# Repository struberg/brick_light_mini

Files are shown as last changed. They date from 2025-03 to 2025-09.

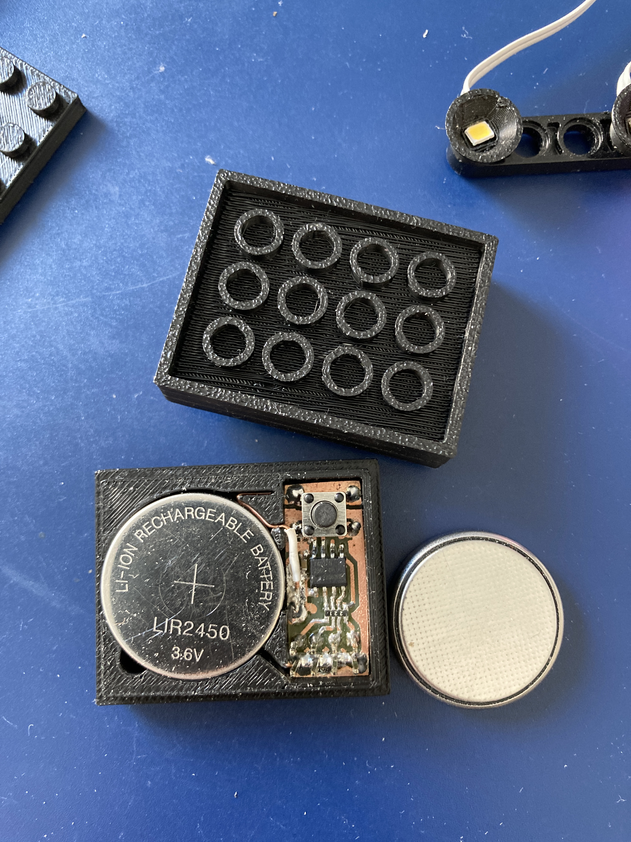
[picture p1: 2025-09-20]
pics/IMG_5117.JPG

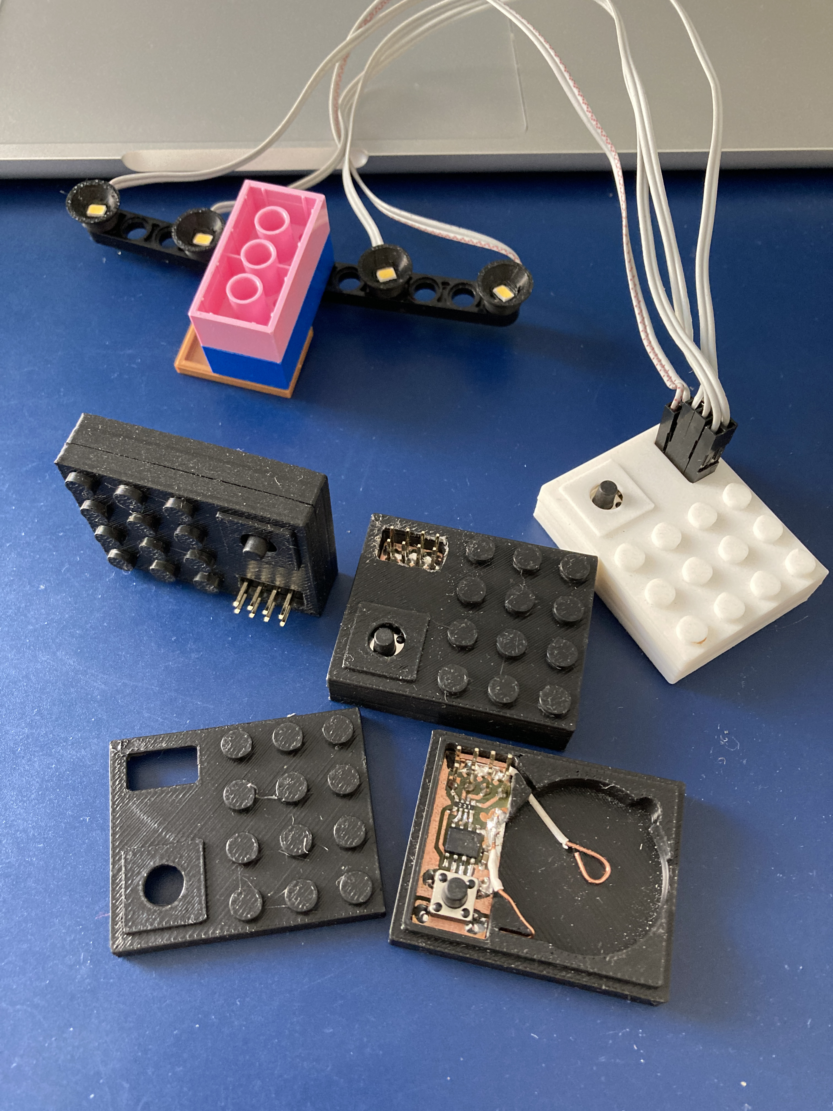
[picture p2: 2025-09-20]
pics/IMG_5110.JPG

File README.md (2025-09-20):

# Lightning system for game bricks

This is a game brick compatible lightning solution to control 4 LEDs.
The repo contains the controller box source code, schematic and PCB plus all the 3d printer models to create your own enclousure and lamps.
The PCB is deliberately single sided and can easily be etched by yourself with Natriumpersulfate.
Ofc if someone likes to create a double sided PCB to be made at Aisler etc then don't hesitate to ship a PR.

The schematic is based on a 0-series ATtiny-402, but a 202 will likely do fine as well.
A rechargable LiIon LIR2450 acts as power source.
The 2450 size is a good compromise between juice and size. 
Connectors are simple 2x1 Dupont types.

The only somewhat non-jellybean part is the 4x220R 0603 resistor array. 
I had to use it because 4 separate resistors would have been too big to fit on the PCB.
You can get those for very cheap from aliexpress or mouser though.

## How to connect the LEDs

You can use any standard low power white or colored LEDs.
The maximum output per LED is around 15 mA.

Place the controler box so that the button is on the lower left side and the LED connectors are on the left upper side.
The top row of the pins is all ground and internally connected.
The lower row of the pins are the positive LED pins, starting with 1 on the left side.

```
  x  x  x  x
  |  |  |  | 
  1  2  3  4  
  |  |  |  |
  x  x  x  x
```
## How to use

* single click: switch LED 1 on or off
* double click: switch LED 2 on or off
* triple click: switch LED 3 on or off
* quadruple click: switch LED 4 on or off

The device will switch off all LEDS and go to sleep after around 5 Minutes of not using the button.
This prevents emptying the battery when one forgets to turn off all lights.
The sleep current is in the µA range, I measured from 0.2µA to 1.5µA
The device will turn on again simply by pressing the button.

Have fun!

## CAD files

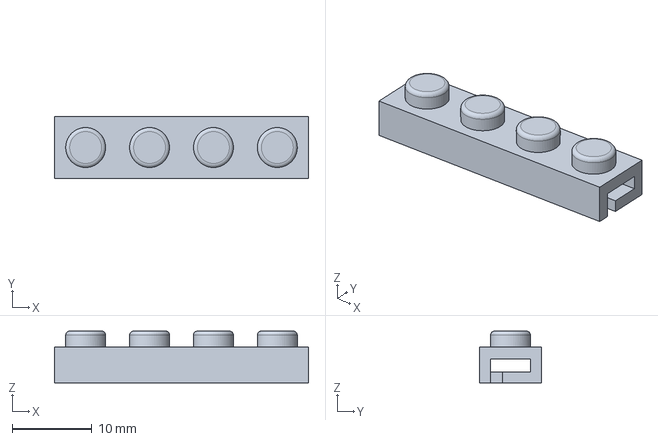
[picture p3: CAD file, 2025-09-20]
freecad/Kabelhalter 4x1.FCStd
31.8 x 7.80 x 6.50 mm

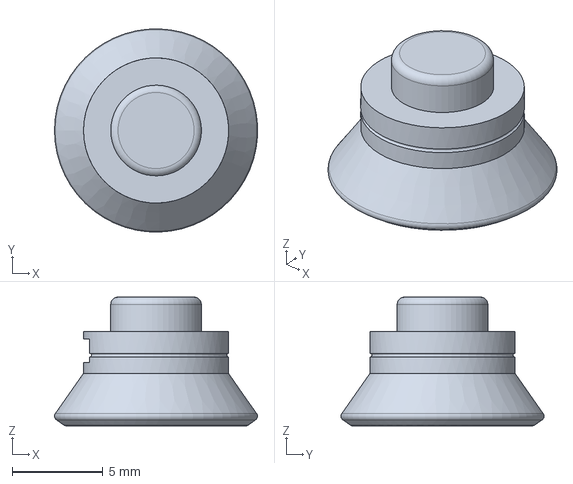
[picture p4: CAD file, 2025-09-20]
freecad/LampeOben.FCStd
11.2 x 11.2 x 7.10 mm

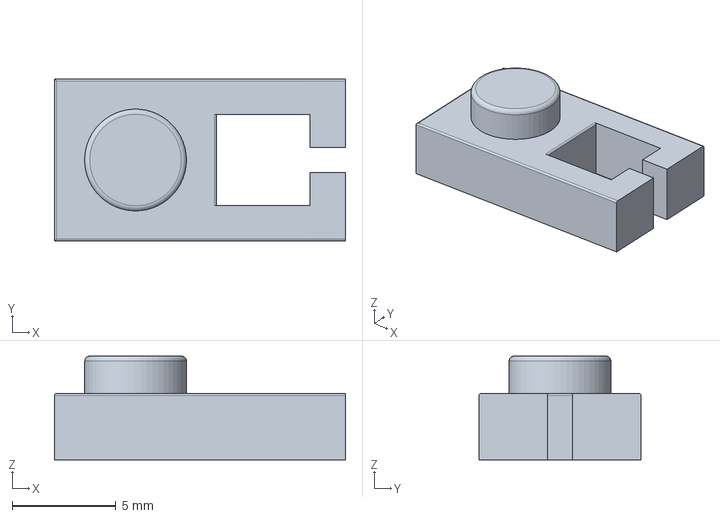
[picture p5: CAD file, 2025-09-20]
freecad/KabelhalterUnten_v.FCStd
14.0 x 7.80 x 5.00 mm

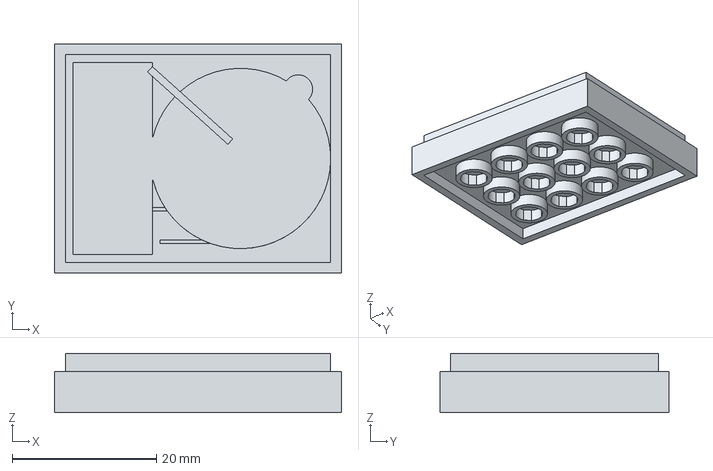
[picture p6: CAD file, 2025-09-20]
freecad/LegoBat_CR2450-bottom.step
39.8 x 31.8 x 8.20 mm

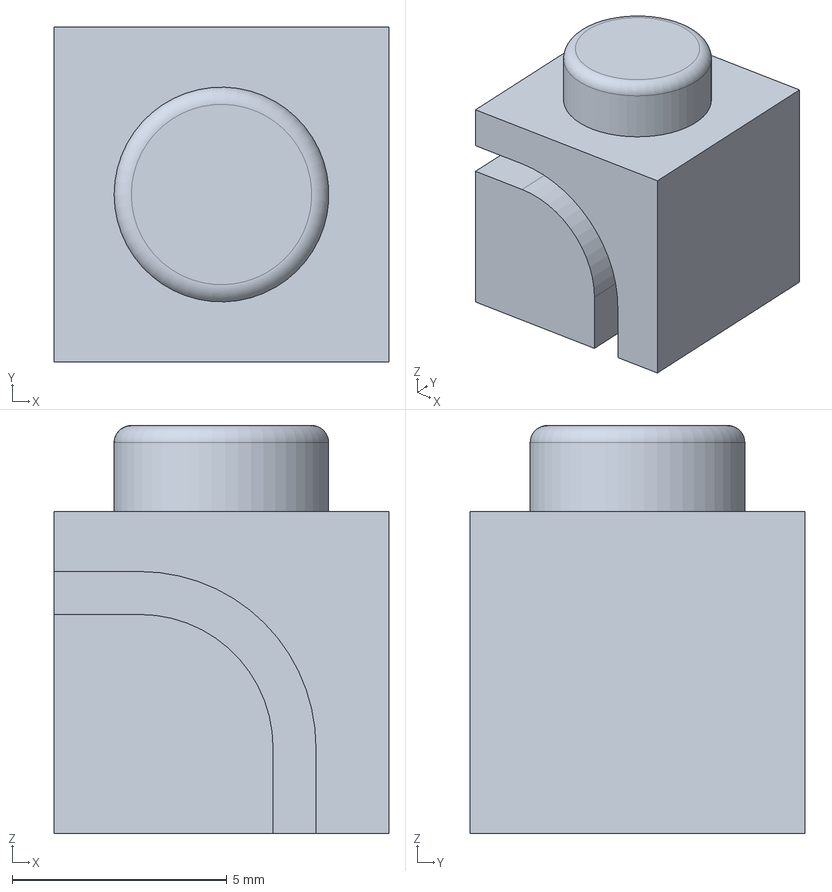
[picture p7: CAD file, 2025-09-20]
freecad/KabelhalterEcke.FCStd
7.80 x 7.80 x 9.50 mm

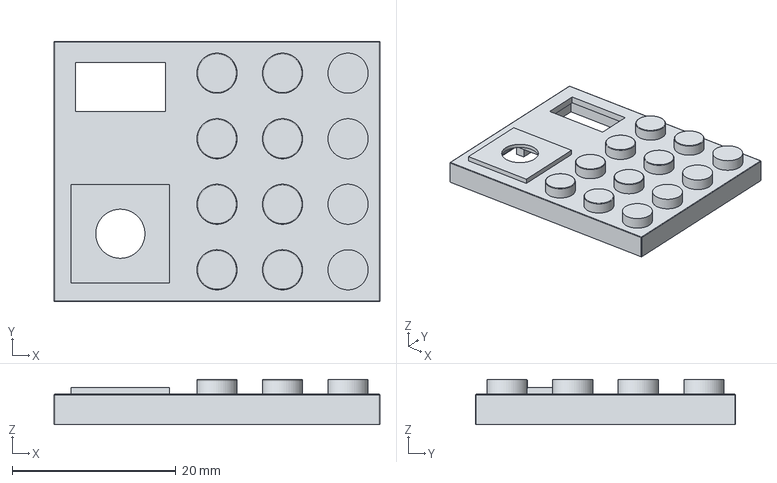
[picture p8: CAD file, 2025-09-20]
freecad/LegoBat_CR2450-top.step
39.8 x 31.8 x 5.50 mm

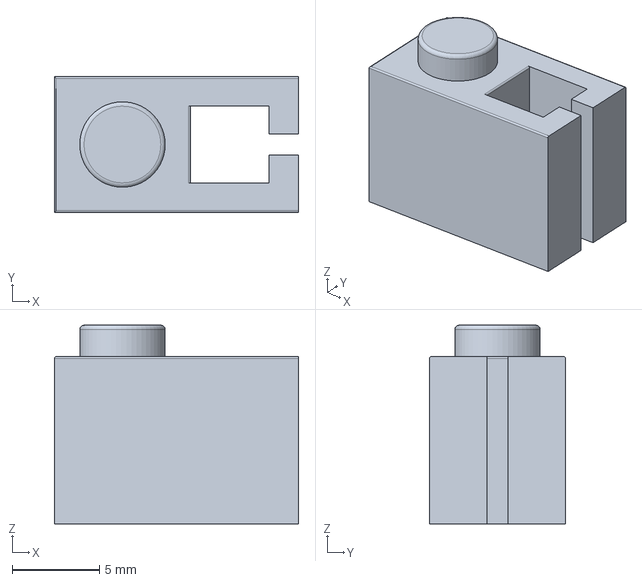
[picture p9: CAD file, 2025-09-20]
freecad/KabelhalterUnten_1x1x3_v.FCStd
14.0 x 7.80 x 11.4 mm

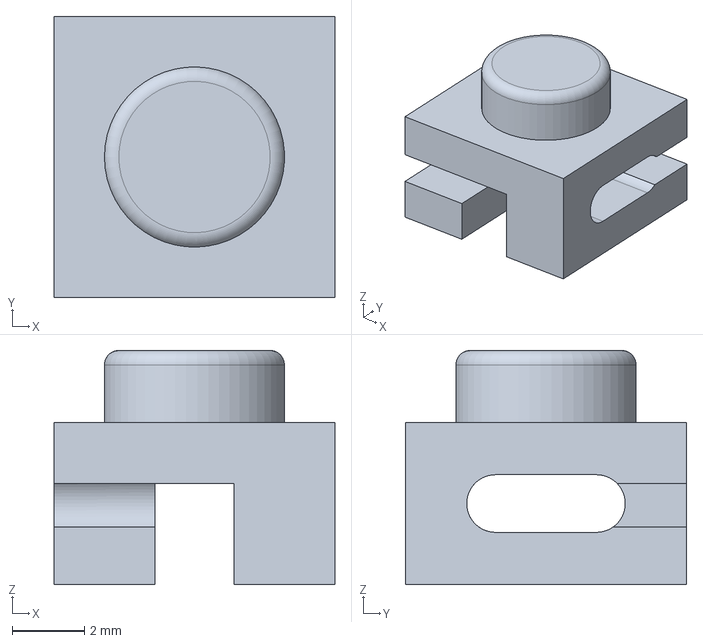
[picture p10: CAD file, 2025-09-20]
freecad/KabelhalterOben.FCStd
7.80 x 7.80 x 6.50 mm

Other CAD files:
freecad/LegoBat_CR2450.FCStd

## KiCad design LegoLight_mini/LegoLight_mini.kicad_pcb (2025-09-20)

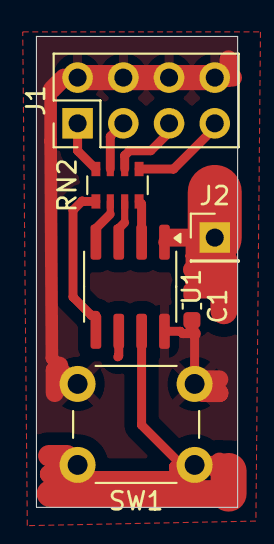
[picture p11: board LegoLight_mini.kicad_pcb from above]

Board: 2 copper layers, 11.2 x 26.2 mm, 6 parts (0 on the bottom side), 11 nets.

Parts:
C1: 1u; C_0603_1608Metric
J1: Conn_02x04_Odd_Even; PinHeader_2x04_P2.54mm_Vertical
J2: +bat; PinHeader_1x01_P2.54mm_Vertical
RN2: 220R; R_Array_Convex_4x0603
SW1: SW_Push; SW_PUSH_6mm_H7.3mm
U1: ATtiny402-SS; SOIC-8_3.9x4.9mm_P1.27mm

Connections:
/Btn: SW1.1, U1.7 (PA3)
/L1: RN2.1 (R1.1), U1.5 (PA2)
/L2: RN2.2 (R2.1), U1.4 (PA1)
/L3: RN2.3 (R3.1), U1.3 (PA7)
/L4: RN2.4 (R4.1), U1.2 (PA6)
GND: C1.2, J1.2, J1.4, J1.6, J1.8, SW1.2, U1.8 (GND)
unnamed: J1.1, RN2.8 (R1.2)
unnamed: J1.3, RN2.7 (R2.2)
unnamed: J1.5, RN2.6 (R3.2)
unnamed: J1.7, RN2.5 (R4.2)
VCC: C1.1, J2.1, U1.1 (VCC)

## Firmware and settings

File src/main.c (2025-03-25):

#include <avr/io.h>
#include <avr/sleep.h>
#include <util/delay.h>
#include <avr/interrupt.h>
#include <stdbool.h>
#include <string.h>

#include "avr_common/strub_common.h"
#include "avr_common/pt.h"



/**
 * @brief small lighting solution for 4 LEDs
 * 
 * L1   PA2 pin5
 * L2   PA1 pin4
 * L3   PA7 pin3
 * L4   PA6 pin2
 * Btn  PA3 pin7
 */

#define BTN_PORT PORTA
#define BTN_PIN PIN3_bm
#define BTN_PIN_CTRL PORTA_PIN3CTRL

#define BTN_SHORT_TIME_MIN 0x05
#define BTN_SHORT_TIME_MAX 0x40
#define BTN_LONG_TIME_MON  0x0120

#define LED_PORT PORTA
#define LED_1_PIN PIN2_bm
#define LED_2_PIN PIN1_bm
#define LED_3_PIN PIN7_bm
#define LED_4_PIN PIN6_bm

#define TASK_TIMEOUT_bm    0x02
#define TASK_INPUT_bm  0x04
#define TASK_ADC_bm    0x08

#define SHUTDODWN_TIME 0xFF00;

volatile uint8_t taskTriggered = 0; 



void setup_cpu(void) {
    // auf prescaler /16 stellen
    // damit rennt die CPU dann effektiv auf 1,33 MHz
    // attention, this needs the CCP (Configuration Change Protection) procedure!

    CCP = CCP_IOREG_gc;
    CLKCTRL.MCLKCTRLB = (0x03 << 1) | 0x01; // clk / 16

    CLKCTRL.MCLKCTRLA = 0x00;
}


void setup_task_timer(void) {
    TASK_TIMER.CCMP = TASK_TIMER_OVERFLOW; /* Compare or Capture */

    TASK_TIMER.CTRLB = 0 | TCB_CNTMODE_INT_gc; // stick at periodic interrupt mode

    TASK_TIMER.CTRLA = TCB_CLKSEL_CLKDIV1_gc  /* CLK_PER (without Prescaler) */
                    | 1 << TCB_ENABLE_bp   /* Enable: enabled */
                    | 0 << TCB_RUNSTDBY_bp /* Run Standby: disabled */
                    | 0 << TCB_SYNCUPD_bp; /* Synchronize Update: disabled */


    // enable Overflow Interrupt. TOP is CCMP
    TASK_TIMER.INTCTRL = TCB_CAPT_bm;
}

volatile uint16_t timers[3] = {0,};

/**
 * @brief TimerB0 overflow
 * 
 * Setzt die 'taskTriggered' bitmask auf FF.
 * Jeder Task kann dann selber checken ob er schon dran war 
 * indem er ein bit darin repräsentiert.
 */
ISR (TCB0_INT_vect) {
    for (uint8_t i=0; i< 3; i++) {
        if (timers[i] > 0) {
            timers[i]--;
        }
    }
    taskTriggered = 0xFF;

    // special handling in the new tinys. one needs to reset the int flags manually 
    TCB0.INTFLAGS = TCB_CAPT_bm;
}

/**
 * @brief wake up from power down
 */
ISR(PORTA_PORT_vect) {
    // clear any subsequent int flag on the pin

    BTN_PORT.INTFLAGS = 0xFF; // writing 1 will clear the int flags

    // disable the PIN interrupt
    BTN_PIN_CTRL &= ~0x03;
}

void setup_io(void) {
    // set leds to output

    LED_PORT.DIRSET = LED_1_PIN | LED_2_PIN | LED_3_PIN | LED_4_PIN;

    // Button input
    BTN_PORT.DIRCLR = BTN_PIN;
    BTN_PIN_CTRL = PORT_PULLUPEN_bm;
}

void setup_adc(void) {
    // setup the voltage reference
    // only used for measuring the VDD itself
    VREF.CTRLA = VREF_ADC0REFSEL_1V5_gc;
    VREF.CTRLB = VREF_ADC0REFEN_bm;

    // ADC itself
    ADC0.CTRLB = 0; // no accumulation

    ADC0.CTRLC = ADC_REFSEL_VDDREF_gc | ADC_PRESC_DIV256_gc;

    ADC0.CTRLD = ADC_INITDLY_DLY64_gc;

    ADC0.MUXPOS = ADC_MUXPOS_INTREF_gc;

    ADC0.CTRLA =  ADC_RESSEL_10BIT_gc | ADC_ENABLE_bm;
}

void adc_enable(void) {
    ADC0.CTRLA |= ADC_ENABLE_bm;
}

void adc_disable(void) {
    ADC0.CTRLA &= ~ADC_ENABLE_bm;
}

void adc_start(void) {
    ADC0.COMMAND |= ADC_STCONV_bm;
}

bool adc_finished(void) {
    return ADC0.INTFLAGS & ADC_RESRDY_bm;
}


void enable_pin_change_interrupt(void) {
    // disable the PIN interrupt
    BTN_PORT.INTFLAGS = 0xFF;
    BTN_PIN_CTRL = PORT_PULLUPEN_bm | PORT_ISC_BOTHEDGES_gc;
}

void disable_pin_change_interrupt(void) {
    // disable the PIN interrupt
    BTN_PIN_CTRL &= ~0x07;
}


void power_down(void) {
    LED_PORT.OUTCLR = LED_1_PIN | LED_2_PIN | LED_3_PIN | LED_4_PIN;

    set_sleep_mode(SLEEP_MODE_PWR_DOWN);
    sleep_enable();
    enable_pin_change_interrupt();
    sleep_cpu();
    sleep_disable();
    disable_pin_change_interrupt();
}


void executeCommand(uint8_t command) {
    // reset timeout;
    timers[0] = SHUTDODWN_TIME;

    switch (command) {
        case 1:
            LED_PORT.OUTTGL = LED_1_PIN;
            break;
        case 2:
            LED_PORT.OUTTGL = LED_2_PIN;
            break;
        case 3:
            LED_PORT.OUTTGL = LED_3_PIN;
            break;
        case 4:
            LED_PORT.OUTTGL = LED_4_PIN;
            break;
    
        default:
            break;
    }

    timers[1] = 0xFFFF;
}

bool buttonPressed(void) {
    return !(BTN_PORT.IN & BTN_PIN);
}

void task_input(void) {
    static uint16_t btnOnTime = 0;
    static uint16_t btnOffTime = 0;
    static uint8_t btnClicks = 1;
    
    if (taskTriggered & TASK_INPUT_bm) {
        taskTriggered &= ~TASK_INPUT_bm;

        if (buttonPressed()) {
            btnOnTime++;

            if (btnOffTime > 0) {
                if (btnOffTime < BTN_SHORT_TIME_MAX) {
                    btnClicks++;
                }
                else {
                    btnClicks = 1;
                }

                btnOffTime = 0;
            }
        }
        else {
            if (btnOnTime > 0 && btnOffTime > BTN_SHORT_TIME_MAX) {
                executeCommand(btnClicks);
                btnOnTime = 0;
                btnOffTime = 0;
            }
            if (btnOffTime < 0xFFFF) {
                btnOffTime++;
            }
        }

    }
}

struct t_adc_state {
    struct pt pt;
    uint8_t blink;
    uint16_t timer;
} adc_state = {0,};


PT_THREAD(task_adc(void)) {
    PT_BEGIN(&adc_state.pt);

    if (taskTriggered & TASK_ADC_bm) {
        // only once per timer interrupt
        taskTriggered &= ~TASK_ADC_bm;
        if (adc_state.timer > 0) {
            adc_state.timer--;
            PT_YIELD(&adc_state.pt);
        }            
        adc_state.timer = 50;

        adc_enable();
        adc_start();


        PT_YIELD_UNTIL(&adc_state.pt, adc_finished());

        uint16_t val = ADC0.RES;
        adc_disable();

        if (val >= 500) {
            // Vdd < 3V now
            // let's start a short blink, then turn off
            LED_PORT.OUTSET = LED_1_PIN | LED_2_PIN | LED_3_PIN | LED_4_PIN;
            timers[1] = 50;
            PT_YIELD_UNTIL(&adc_state.pt, timers[1] == 0);

            power_down();
        }
    }
    
    PT_END(&adc_state.pt);
}

void task_timeout(void) {
    if (taskTriggered & TASK_TIMEOUT_bm) {
        // only once per timer interrupt
        taskTriggered &= ~TASK_TIMEOUT_bm;

        if (timers[0] == 0) {
            power_down();
            timers[0] = SHUTDODWN_TIME;
        }
    }
}

int main(void) {
    setup_cpu();
    setup_task_timer();

    setup_io();
    setup_adc();


    timers[0] = SHUTDODWN_TIME;

    sei();

    while(1) {
        task_adc();
        task_input();
        task_timeout();
    }

    return 1;
}

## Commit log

2025-03-25 ADC for low bat voltage detection
    In case of Ubat lower 3.1 V we blink all lights
    and switch into standby mode.
    [LegoLight_mini.kicad_pcb, LegoLight_mini.kicad_sch]
2025-09-20 adding freecad models
    [Kabelhalter 4x1.FCStd, KabelhalterEcke.FCStd, KabelhalterOben.FCStd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]
